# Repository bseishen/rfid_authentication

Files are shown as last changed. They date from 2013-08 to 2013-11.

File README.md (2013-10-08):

# Overview

[Midsouth Makers](www.midsouthmakers.org) RFID access based on a [Beagle Bone Black](http://beagleboard.org/Products/BeagleBone%20Black) and a cheap Chinese wiegand reader.

# How To

## Add user
You must be a part of the administrator group to add users.

### Via the Keypad
Scan rfid token and enter your 4 digit pin.
Press the 3 key. Light will flash green and beep once completed. This will enter add user mode. Esc can be hit to exit this mode.
Scan the new RFID token, and have user enter a 4 digit pin.
Light will flash green and beep once completed successfully.

### Via the Web Interface
TODO: add content

## Delete user
You must be a part of the administrator group to add users.

### Via the Keypad
Scan rfid token and enter your 4 digit pin.
Press the 4 key. Light will flash green and beep once completed. This will enter add user mode. Esc can be hit to exit this mode.
Scan the new RFID token, and have user enter a 4 digit pin.
Light will flash green and beep once completed successfully.
Technical Details

# Source Code
All Code is located on a github repository located at: https://github.com/bseishen/rfid_authentication/

# Wiegand Reader
Reader is a 26bit Chinese special. MSB and LSB are parity bits, the remainging 24bits are the LSB of the RFID token.

Couple of gotcha's with this reader:
* Numeric key presses are sent without parity and are only 16bits.
* Buzzer lines or status led cannot be held low when trying to read data from the reader.

## Panel
## Pin Assignements
* Relay 1 - `GPIO_67` - Garage Door
* Relay 2 - `GPIO_66` - Front Door
* Relay 3 - `GPIO_44` - Buzzer
* Relay 4 - `GPIO_45` - Status LED
* Relay 5 - `GPIO_26` - UNASSIGNED
* Relay 6 - `GPIO_23` - UNASSIGNED
* Relay 7 - `GPIO_46` - UNASSIGNED
* Relay 8 - `GPIO_47` - Strobe
* `GPIO_68` - Wiegand D0
* `GPIO_69` - Wiegand D1
* `GPIO_02` - 1 wire for temperature sensor

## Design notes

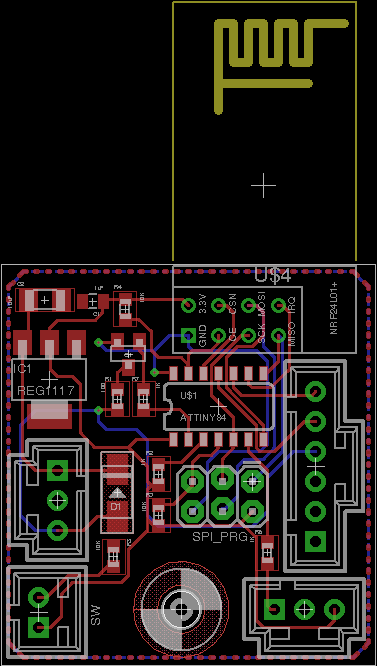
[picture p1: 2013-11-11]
Hardware/Squid_Leg_Controller.png

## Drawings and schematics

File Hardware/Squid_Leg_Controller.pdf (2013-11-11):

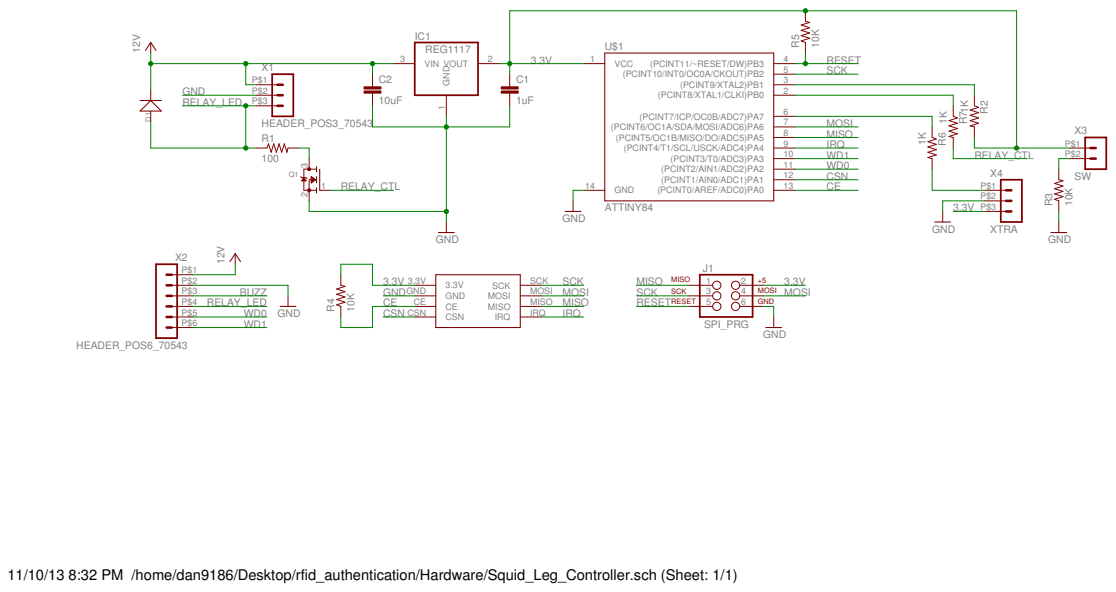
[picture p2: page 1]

11/10/13 8:32 PM /home/dan9186/Desktop/rfid_authentication/Hardware/Squid_Leg_Controller.sch (Sheet: 1/1)

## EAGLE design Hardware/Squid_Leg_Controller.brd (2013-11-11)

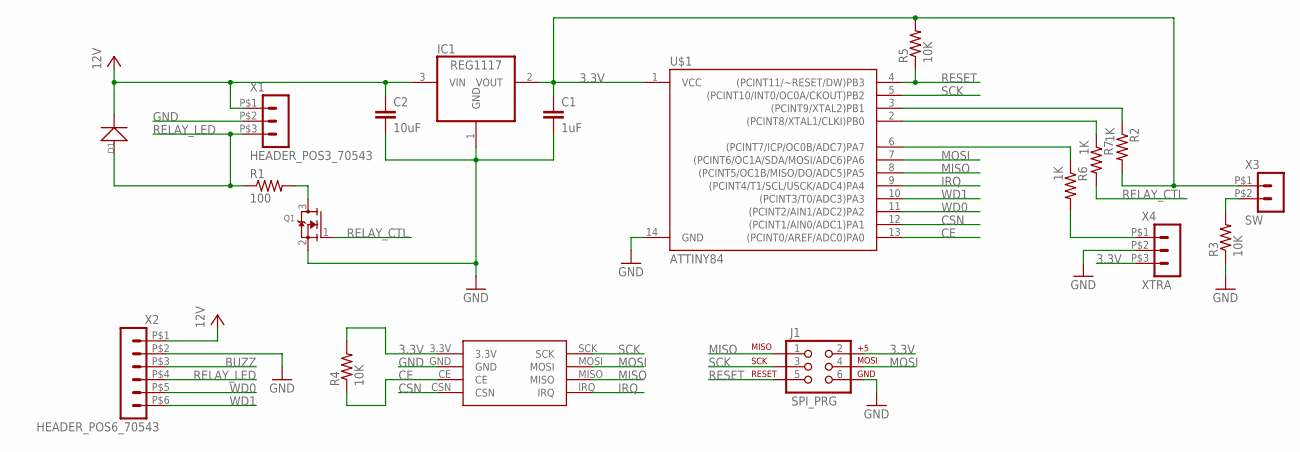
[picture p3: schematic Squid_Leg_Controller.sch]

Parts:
C1: 1uF; 0805
C2: 10uF; 1206
D1: D-SMA; DO-214AC
IC1: REG1117; SOT223
J1: SPI_PRG; 2X3_LOCK
Q1: MOSFET-NREFLOW; SOT23
R1: 100; R0603
R2, R6, R7: 1K; R0603
R3, R4, R5: 10K; R0603
U$1: ATTINY84; SO14
U$4: NRF24L01+; NRF24L01+_MODULE_OFFBRD
X1: HEADER_POS3_70543; 70543-POS3
X2: HEADER_POS6_70543; 70543-POS6
X3: SW; 70543-POS2
X4: XTRA; 70543-POS3

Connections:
3.3V: C1.1, IC1.2 (VOUT), J1.2, R2.2, R4.2, R5.2, U$1.1 (VCC), U$4.3.3V, X3.P$1 (1), X4.P$3 (3)
BUZZ: X2.P$3 (3)
CE: R4.1, U$1.13 ((PCINT0/AREF/ADC0)PA0), U$4.CE
CSN: U$1.12 ((PCINT1/AIN0/ADC1)PA1), U$4.CSN
GND: C1.2, C2.2, IC1.1 (GND), J1.6, Q1.2 (S), R3.1, U$1.14 (GND), U$4.GND, X1.P$2 (2), X2.P$2 (2), X4.P$2 (2)
IRQ: U$1.9 ((PCINT4/T1/SCL/USCK/ADC4)PA4), U$4.IRQ
MISO: J1.1, U$1.8 ((PCINT5/OC1B/MISO/DO/ADC5)PA5), U$4.MISO
MOSI: J1.4, U$1.7 ((PCINT6/OC1A/SDA/MOSI/ADC6)PA6), U$4.MOSI
unnamed: R2.1, U$1.3 ((PCINT9/XTAL2)PB1)
unnamed: R3.2, X3.P$2 (2)
unnamed: R6.1, U$1.6 ((PCINT7/ICP/OC0B/ADC7)PA7)
unnamed: R7.1, U$1.2 ((PCINT8/XTAL1/CLKI)PB0)
unnamed: Q1.3 (D), R1.2
unnamed: R6.2, X4.P$1 (1)
RELAY_CTL: Q1.1 (G), R7.2
RELAY_LED: D1.1 (+), R1.1, X1.P$3 (3), X2.P$4 (4)
RESET: J1.5, R5.1, U$1.4 ((PCINT11/~RESET/DW)PB3)
SCK: J1.3, U$1.5 ((PCINT10/INT0/OC0A/CKOUT)PB2), U$4.SCK
VCC: C2.1, D1.2 (-), IC1.3 (VIN), X1.P$1 (1), X2.P$1 (1)
WD0: U$1.11 ((PCINT2/AIN1/ADC2)PA2), X2.P$5 (5)
WD1: U$1.10 ((PCINT3/T0/ADC3)PA3), X2.P$6 (6)

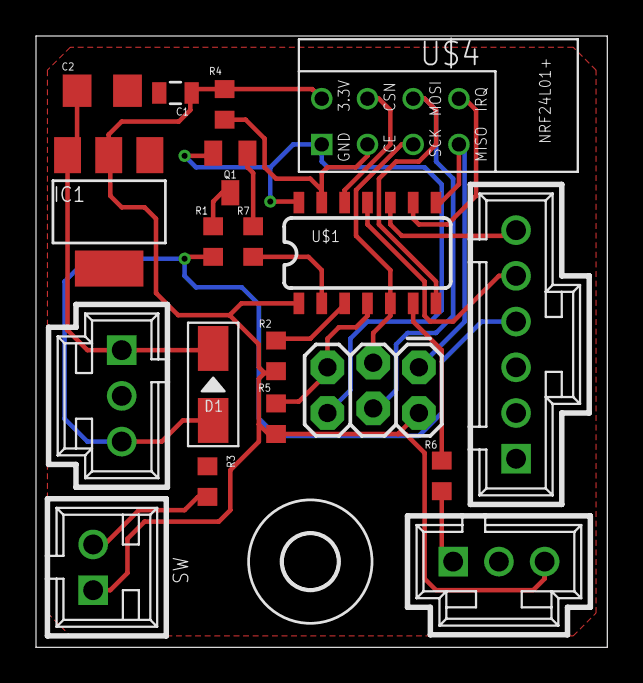
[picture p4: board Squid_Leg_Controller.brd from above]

Board: 2 copper layers, 31.7 x 34.0 mm, 20 parts (0 on the bottom side), 20 nets.

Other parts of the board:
U$2: 3,0

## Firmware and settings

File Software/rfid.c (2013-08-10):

/*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
This library is distributed in the hope that it will be useful,
but WITHOUT ANY WARRANTY; without even the implied warranty of
MERCHANTABILITY or FITNESS FOR A PARTICULAR PURPOSE. See the GNU
Lesser General Public License for more details.
*/
#include <stdio.h>
#include <stdlib.h>
#include <string.h>
#include <errno.h>
#include <unistd.h>
#include <syslog.h>
#include <fcntl.h>
#include <poll.h>
#include <pthread.h>
#include <sys/time.h>
#include <crypt.h>
#include "config.h"
#include "gpio.h"
#include "log.h"
#include "sqlite3.h"

//#define DEBUG_WIEGAND 1
//#define DEBUG	1

#define STATUS_NULL 		0x00
#define STATUS_RFID_READY	0x01
#define STATUS_KEYS_READY	0x02
#define STATUS_AUX_OPTIONS	0x04


pthread_t tid[1];

struct reader_t {
	unsigned char status;				//This is a bit mask field. 0x01-RFID_READY, 0x02-KEYS_READY, 0x04-AUX_OPTIONS_READY
	unsigned int  rfid; 				//RFID key that was read
	unsigned char keys[5];				//Key presses stored in this array
	struct timeval tvPacket; 			//time since the last wiegand packet was recivied, used to timeout the session for inactivity.
};

struct reader_t reader;

unsigned char clear_reader = 0;  		//bit flag used to tell the wiegand routine to flush any temp data.



/**
 * Poll_wiegand polls D0 and D1 for data and fills the reader structure.
 */

void* poll_wiegand(void *arg){
	struct pollfd fdset[2];
	struct timeval tvEnd, tvDiff;
	int nfds = 2;
	int lastPacketType = 0;
	int keyCount=0;
	int temp=0;
	int readerCount=0;
	int gpio_d0, gpio_d1, timePacket, rc;
	char *buf[MAX_BUF];
	char error[255];
	unsigned char charTemp;

	gpio_d0 = gpio_fd_open(WIEGAND_D0_GPIO);
	gpio_d1 = gpio_fd_open(WIEGAND_D1_GPIO);
 
	memset((void*)fdset, 0, sizeof(fdset));

	fdset[0].fd = gpio_d0;
	fdset[0].events = POLLPRI;

	fdset[1].fd = gpio_d1;
	fdset[1].events = POLLPRI;

	//This is needed to flush the first false interrupt
	read(fdset[0].fd, buf, MAX_BUF);
	read(fdset[1].fd, buf, MAX_BUF);

	clear_reader = 1;

	while (1) {
		gettimeofday(&reader.tvPacket, NULL);

		rc = poll(fdset, nfds, -1);

		if (rc < 0) {
			sprintf(error,"Pin interrupt poll failed, fatal error.");
			log_err(error);
		}

		gettimeofday(&tvEnd, NULL);

                timersub(&tvEnd, &reader.tvPacket, &tvDiff);
                timePacket = (tvDiff.tv_sec) * 1000 + (tvDiff.tv_usec) / 1000 ;

		//clear everything if there wasnt a press after 10 seconds.
		if(timePacket>10000)
			clear_reader = 1;

		//packet data over the wiegand is either 26bits for rfid read or 8 bits for a key press.
		//if time from the last packet is under 5ms, treat the last packet as an rfid packet.
		if(lastPacketType == 1){
			//timersub(&tvEnd, &reader.tvPacket, &tvDiff);
			//timePacket = (tvDiff.tv_sec) * 1000 + (tvDiff.tv_usec) / 1000 ;
			lastPacketType = 0;

			if(timePacket < MAX_WIEGAND_PACKET_LENGTH_MS){
				//Delete all key presses. This is a rfid token being read.
				keyCount = 0;
				reader.keys[0] = 0;
				reader.keys[1] = 0;
				reader.keys[2] = 0;
				reader.keys[3] = 0;
				reader.keys[4] = 0;
			}
			else{
				//Last packet was a key press.
				temp = 0;
				readerCount = 0;
				//If an esc key was pressed, clear reader.
				if(reader.keys[0] == 10 || reader.keys[1] == 10 || reader.keys[2] == 10 || reader.keys[3] == 10){
					clear_reader = 1;
#ifdef DEBUG
					printf("ESC KEY WAS PRESSED\n");
#endif
				}
			}
		}

		if(clear_reader == 1){
			reader.status = STATUS_NULL;
			reader.rfid = 0;
			reader.keys[0] = 0;
			reader.keys[1] = 0;
			reader.keys[2] = 0;
			reader.keys[3] = 0;
			reader.keys[4] = 0;
			temp = 0;
			readerCount = 0;
			lastPacketType = 0;
			keyCount = 0;
			clear_reader = 0;
#ifdef DEBUG
			printf("FLUSHING RFID BUFFER\n");
#endif

		}

		//this has been added to flush wiegand trash that shows up from EMI from the door latch.
		if(clear_reader == 2){
#ifdef DEBUG
			printf("ONLY FLUSHING TEMP BUFFER\n");
#endif
			temp = 0;
			readerCount = 0;
			clear_reader = 0;
		}


		if (fdset[0].revents & POLLPRI) {
			read(fdset[0].fd, buf, MAX_BUF);
			temp = temp << 1;
			readerCount++;
		}

		if (fdset[1].revents & POLLPRI) {
			read(fdset[1].fd, buf, MAX_BUF);
			temp = temp << 1;
			temp |= 1;
			readerCount++;
		}


		///Key was pressed, add it to the array
		if(readerCount==WIEGAND_KEY_LENGTH){
			if(keyCount>5){
				keyCount=0;
				reader.status  &= ~(STATUS_KEYS_READY|STATUS_AUX_OPTIONS);
#ifdef DEBUG
				printf("KEY PRESSES EXCEEDED 5 PRESSES, FLUSHING KEY BUFFER\n");
#endif
				fflush(stdout);
			}

			switch(temp){
				case 0xE1:
					charTemp = 1;
					break;
				case 0xD2:
					charTemp = 2;
					break;
				case 0xC3:
					charTemp = 3;
					break;
				case 0xB4:
					charTemp = 4;
					break;
				case 0xA5:
					charTemp = 5;
					break;
				case 0x96:
					charTemp = 6;
					break;
				case 0x87:
					charTemp = 7;
					break;
				case 0x78:
					charTemp = 8;
					break;
				case 0x69:
					charTemp = 9;
					break;
				case 0xF0:
					charTemp = 0;
					break;
				case 0x5A:
					charTemp = 10;
					break;
				case 0x4B:
					charTemp = 11;
					break;
				default:
					charTemp = 0xFF; //DATA WAS GARBAGE
			}

			if(charTemp!=0xFF){
				reader.keys[keyCount] = charTemp;
				//set status bit for keyRead is ready
				if(keyCount == 3){
					reader.status |= STATUS_KEYS_READY;
#ifdef DEBUG
					printf("4 Keys in Buffer \n");
#endif
				}
				if(keyCount == 4){
					reader.status |= STATUS_AUX_OPTIONS;
#ifdef DEBUG
					printf("5 Keys in Buffer \n");
#endif
				}
			}

			keyCount++;
			lastPacketType = 1;
		}

		///RFID data is present, store it.
		if(readerCount == 26){
			//Mask the MSB off and Shift out the LSB. These are the even and odd parity.
			reader.rfid=(temp>>1) & 0x00FFFFFF;
			reader.status |= STATUS_RFID_READY;
			readerCount = 0;
			temp = 0;
			keyCount = 0;
			reader.keys[0] = 0;
			reader.keys[1] = 0;
			reader.keys[2] = 0;
			reader.keys[3] = 0;
			reader.keys[4] = 0;
		}

		if(readerCount > 26){
			//something went wrong
			clear_reader = 1;
		}

#ifdef DEBUG_WIEGAND
		printf("RFID: %X \n", reader.rfid);
		printf("KEYCOUNT: %X \n", keyCount);
		printf("KEY1: %X \n", reader.keys[0]);
		printf("KEY2: %X \n", reader.keys[1]);
		printf("KEY3: %X \n", reader.keys[2]);
		printf("KEY4: %X \n", reader.keys[3]);
		printf("KEY5: %X \n", reader.keys[4]);
		printf("STATUS: %X \n\n", reader.status);
#endif



		fflush(stdout);

	}

	gpio_fd_close(gpio_d0);
	gpio_fd_close(gpio_d1);

}

int main(int argc, char **argv, char **envp)
{

	int retval;
	unsigned char userVerified = 0; 			//0- Not verified, 1-verified, 2-verified as admin
	unsigned int lastKey;
	char *result;
	char buffer[20];
	char hash[40] = "$1$DeaDBeeF$NanaNanaBooBoo//DooDoo";
	char query[200];
	char error[255];
	sqlite3_stmt *stmt;
	sqlite3 *handle;
	struct timeval tvNow, tvDifference, tvAux, tvUnlock;
	int timeMS;
	int keyBuff;


	//init ports
	gpio_init();

	//init tvUnlock, last time of door unlock.
	gettimeofday(&tvUnlock, NULL);

	//init DB
    retval = sqlite3_open(DB_PATH, &handle);
    if(retval)
    {
		sprintf(error,"Sqlite DB failed to INIT!");
		log_err(error);
        return -1;
    }

    sprintf(query,"CREATE TABLE IF NOT EXISTS users (key INTERGER PRIMARY KEY,hash TEXT NOT NULL, ircName TEXT, spokenName TEXT, addedBy TEXT, dateCreated INTERGER, isAdmin INTERGER, lastLogin INTERGER, isActive INTERGER)");
    retval = sqlite3_exec(handle,query,0,0,0);


    //Thread off wiegand poller
	if (pthread_create(&(tid[1]), NULL, &poll_wiegand, NULL)){
		sprintf(error,"Wiegand thread failed to start.");
		log_err(error);
	}


	fflush(stdout);

	while(1){
		usleep(500000);

		//get time passed since last wiegand packet
		gettimeofday(&tvNow, NULL);
		timersub(&tvNow, &tvUnlock, &tvDifference);
		timeMS = (tvDifference.tv_sec) * 1000 + (tvDifference.tv_usec) / 1000 ;
#ifdef DEBUG
//		printf("Timer: %d",timeMS);
#endif
		///Clear if timeout has exceeded threshold. Lock everything!
		if(timeMS>TIMEOUT_DOORLOCK && userVerified > 0){
			lock_door();
			led_off();
			beep_off();
			usleep(250000);
			printf("DOOR LOCKING!!!!!!!!!!!!!!\n");
			clear_reader = 1;
			userVerified = 0;
		}
#ifdef DEBUG
		//printf("READER STATUS: %d \n",reader.status);
#endif
		//Authenticate User
		if(userVerified == 0 && clear_reader == 0 &&(reader.status == (STATUS_RFID_READY|STATUS_KEYS_READY) || reader.status == (STATUS_RFID_READY|STATUS_KEYS_READY|STATUS_AUX_OPTIONS))){
			keyBuff = (reader.keys[0]*1000)+(reader.keys[1]*100)+(reader.keys[2]*10)+reader.keys[3];
			sprintf(query, "SELECT * from users WHERE key='%d'" , reader.rfid);
			retval = sqlite3_prepare_v2(handle,query,-1,&stmt,0);
			if(retval){
				sprintf(error,"Query returned and error.");
				log_err(error);
			}
			else{

				while(1)
				    {
				        retval = sqlite3_step(stmt);

				        if(retval == SQLITE_ROW)
				        {
				        	const char *val = (char *)sqlite3_column_text(stmt,1);
				        	sprintf(hash, "%s", val);
				        }
				        else if(retval == SQLITE_DONE)
				        {
				            // All rows finished
				            break;
				        }
				        else
				        {
				            // Some error encountered
							sprintf(error,"SQLite shit the bed.");
							log_err(error);
				        }
				    }

				sprintf(buffer, "%d", keyBuff);
				result = crypt(buffer, hash);
				sprintf(query, "SELECT * from users WHERE key='%d'" , reader.rfid);
				retval = sqlite3_exec(handle,query,0,0,0);
				if(retval){
					sprintf(error,"Query returned and error.");
					log_err(error);
				}
				else{
					while(1){
						// fetch a row's status
						retval = sqlite3_step(stmt);

						if(retval == SQLITE_ROW){
				        	const char *val = (char *)sqlite3_column_text(stmt,1);
				        	sprintf(hash, "%s", val);
				        	if(strcmp(hash,result)==0){
				        		//Check if user is active.
				        		if(sqlite3_column_int(stmt,8)){
				        			userVerified= 1;
				        			//Check if user is an admin.
				        			if(sqlite3_column_int(stmt,6)){
				        				userVerified = 2;
				        			}
				        		}
				        	}
						}
						else if(retval == SQLITE_DONE){
							// All rows finished
							break;
						}
						else{
							// Some error encountered
							sprintf(error,"SQLite shit the bed.");
							log_err(error);
							return -1;
						}
					}
				}


				if(userVerified > 0){
					sprintf(error,"Access granted to user %d", reader.rfid);
					log_err(error);
					//clear temp buffer and grab last rfid key
					lastKey=reader.rfid;
					//Possibly need to clear reader temp

					//Update User's last login time
					sprintf(query, "UPDATE users SET lastLogin='%d' WHERE key='%d'" ,(int)tvNow.tv_sec, reader.rfid);
					retval = sqlite3_prepare_v2(handle,query,-1,&stmt,0);
					if(retval){
						sprintf(error,"Query returned and error.");
						log_err(error);
					}

					retval = sqlite3_step(stmt);

					gettimeofday(&tvUnlock, NULL);

					unlock_door();
					usleep(100000);
					clear_reader = 2;
					//led_on();

					//TODO:log user in logs, notify irc, play welcome message.

				}
				else{
					sprintf(error,"ACCESS DENIED to user %d", reader.rfid);
					log_err(error);
					clear_reader = 1;
					led_blink(2);
				}
			}
		}

		//delete user (using 4 key on keypad)
		if(userVerified == 2 && reader.keys[4]==4){
			lastKey = reader.rfid;
			sprintf(error,"Delete user mode entered by user ID: %d", reader.rfid);
			log_err(error);
			clear_reader = 1;
			beep_on();
			sleep(1);
			beep_off();

			//Wait for rfid to be scanned. Cancels if ESC key is pressed.
			while(reader.status!= (STATUS_RFID_READY|STATUS_KEYS_READY)){
				if(reader.keys[0]==10 || reader.keys[1]==10 ||reader.keys[2]==10 ||reader.keys[3]==10 ||reader.keys[4]==10){
					retval = 1;
					break;
				}

				gettimeofday(&tvAux, NULL);
				timersub(&tvAux, &tvNow, &tvDifference);
				timeMS = (tvDifference.tv_sec) * 1000 + (tvDifference.tv_usec) / 1000 ;
				if(timeMS > 20000){
					retval = 1;
					break;
				}

				sleep(.1);

			}

			//if ESC key was pressed or if admin key was scanned twice.
			if(retval || reader.rfid == lastKey){
				sprintf(error,"Delete user mode exited by %d. No user deleted.",reader.rfid);
				log_err(error);
			}
			else{
				sprintf(query, "DELETE FROM users WHERE key='%d'" , reader.rfid);
				retval = sqlite3_prepare_v2(handle,query,-1,&stmt,0);
				retval = sqlite3_step(stmt);

				if(retval == SQLITE_DONE){
					sprintf(error,"User %d deleted from DB by User %d",reader.rfid, lastKey);
					log_err(error);
				}

				beep_on();
				sleep(1);
				beep_off();
			}

			clear_reader = 1;
			fflush(stdout);
		}
#ifdef ADD_FIRST_USER
		userVerified = 2;
		reader.keys[4]=11;
#endif
		//add new user (using 3 key on keypad)
		if(userVerified == 2 && reader.keys[4]==3){
			lastKey = reader.rfid;

			sprintf(error,"Add user mode entered by user %d",reader.rfid);
			log_err(error);

			clear_reader = 1;
			beep_on();
			sleep(1);
			beep_off();

			retval = 0;
			//Wait for rfid and keys to be pressed for the new user. Cancels if ESC key is pressed or takes longer than 20sec.
			while(reader.status!=(STATUS_RFID_READY|STATUS_KEYS_READY)){
				if(reader.keys[0]==10 || reader.keys[1]==10 ||reader.keys[2]==10 ||reader.keys[3]==10 ||reader.keys[4]==10){
					retval = 1;
					break;
				}

				gettimeofday(&tvAux, NULL);
				timersub(&tvAux, &tvNow, &tvDifference);
				timeMS = (tvDifference.tv_sec) * 1000 + (tvDifference.tv_usec) / 1000 ;
				if(timeMS > 20000){
					retval = 1;
					break;
				}

				sleep(.1);

			}

			//if ESC key was pressed
			if(retval || reader.rfid == lastKey){
				sprintf(error,"Add user mode exited, no users were added.");
				log_err(error);
			}
			else{
				unsigned long seed[2];
			    char salt[] = "$1$........";
			    const char *const seedchars ="./0123456789ABCDEFGHIJKLMNOPQRSTUVWXYZabcdefghijklmnopqrstuvwxyz";
			    int i;

			    /* Generate a (not very) random seed.
			       You should do it better than this... */
			    seed[0] = time(NULL);
			    seed[1] = getpid() ^ (seed[0] >> 14 & 0x30000);

			    /* Turn it into printable characters from `seedchars'. */
			    for (i = 0; i < 8; i++)
			      salt[3+i] = seedchars[(seed[i/5] >> (i%5)*6) & 0x3f];


				keyBuff = (reader.keys[0]*1000)+(reader.keys[1]*100)+(reader.keys[2]*10)+reader.keys[3];

				sprintf(buffer, "%d", keyBuff);
				result = crypt(buffer, salt);

#ifdef ADD_FIRST_USER
				sprintf(query, "INSERT INTO users VALUES('%d','%s','','','%d','%d',1,0,1)" , reader.rfid, result, lastKey, (int)tvNow.tv_sec);
#else
				sprintf(query, "INSERT INTO users VALUES('%d','%s','','','%d','%d',0,0,1)" , reader.rfid, result, lastKey, (int)tvNow.tv_sec);
#endif
				retval = sqlite3_prepare_v2(handle,query,-1,&stmt,0);
				retval = sqlite3_step(stmt);

				if(retval == SQLITE_DONE){
					sprintf(error,"User %d was added to the DB by user %d", reader.rfid, lastKey);
					log_err(error);
				}

				beep_on();
				sleep(1);
				beep_off();

			}
			clear_reader = 1;
		}

		//OpenGarageDoor (using number 2 on keypad)
		if(userVerified > 0 && reader.keys[4]==2){
			sprintf(error,"Garage door toggled by user %d", reader.rfid);
			log_err(error);
			clear_reader = 1;
			toggle_garage();
		}


		fflush(stdout);

	}

	pthread_join(tid[1], NULL);

	sqlite3_close(handle);

	return 0;
}

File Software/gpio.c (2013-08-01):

/*
 * All rights reserved.
 * 
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
 * THIS SOFTWARE IS PROVIDED BY RIDGERUN ''AS IS'' AND ANY
 * EXPRESS OR IMPLIED WARRANTIES, INCLUDING, BUT NOT LIMITED TO, THE IMPLIED
 * WARRANTIES OF MERCHANTABILITY AND FITNESS FOR A PARTICULAR PURPOSE ARE
 * DISCLAIMED. IN NO EVENT SHALL RIDGERUN BE LIABLE FOR ANY
 * DIRECT, INDIRECT, INCIDENTAL, SPECIAL, EXEMPLARY, OR CONSEQUENTIAL DAMAGES
 * (INCLUDING, BUT NOT LIMITED TO, PROCUREMENT OF SUBSTITUTE GOODS OR SERVICES;
 * LOSS OF USE, DATA, OR PROFITS; OR BUSINESS INTERRUPTION) HOWEVER CAUSED AND
 * ON ANY THEORY OF LIABILITY, WHETHER IN CONTRACT, STRICT LIABILITY, OR TORT
 * (INCLUDING NEGLIGENCE OR OTHERWISE) ARISING IN ANY WAY OUT OF THE USE OF THIS
 * SOFTWARE, EVEN IF ADVISED OF THE POSSIBILITY OF SUCH DAMAGE.
 */

#include "gpio.h"

 /****************************************************************
 * Constants
 ****************************************************************/
 
#define SYSFS_GPIO_DIR "/sys/class/gpio"
#define POLL_TIMEOUT (3 * 1000) /* 3 seconds */
#define MAX_BUF 64

/****************************************************************
 * gpio_export
 ****************************************************************/
int gpio_export(unsigned int gpio)
{
	int fd,len;
	char buf[MAX_BUF];
 
	fd = open(SYSFS_GPIO_DIR "/export", O_WRONLY);
	if (fd < 0) {
		perror("gpio/export");
		return fd;
	}
 
	len = snprintf(buf, sizeof(buf), "%d", gpio);
	write(fd, buf, len);
	close(fd);
 
	return 0;
}

/****************************************************************
 * gpio_unexport
 ****************************************************************/
int gpio_unexport(unsigned int gpio)
{
	int fd, len;
	char buf[MAX_BUF];
 
	fd = open(SYSFS_GPIO_DIR "/unexport", O_WRONLY);
	if (fd < 0) {
		perror("gpio/export");
		return fd;
	}
 
	len = snprintf(buf, sizeof(buf), "%d", gpio);
	write(fd, buf, len);
	close(fd);
	return 0;
}

/****************************************************************
 * gpio_set_dir
 ****************************************************************/
int gpio_set_dir(unsigned int gpio, unsigned int out_flag)
{
	int fd;
	char buf[MAX_BUF];
 
	snprintf(buf, sizeof(buf), SYSFS_GPIO_DIR  "/gpio%d/direction", gpio);
 
	fd = open(buf, O_WRONLY);
	if (fd < 0) {
		perror("gpio/direction");
		return fd;
	}
 
	if (out_flag)
		write(fd, "out", 4);
	else
		write(fd, "in", 3);
 
	close(fd);
	return 0;
}

/****************************************************************
 * gpio_set_value
 ****************************************************************/
int gpio_set_value(unsigned int gpio, unsigned int value)
{
	int fd;
	char buf[MAX_BUF];
 
	snprintf(buf, sizeof(buf), SYSFS_GPIO_DIR "/gpio%d/value", gpio);
 
	fd = open(buf, O_WRONLY);
	if (fd < 0) {
		perror("gpio/set-value");
		return fd;
	}
 
	if (value)
		write(fd, "1", 2);
	else
		write(fd, "0", 2);
 
	close(fd);
	return 0;
}

/****************************************************************
 * gpio_get_value
 ****************************************************************/
int gpio_get_value(unsigned int gpio, unsigned int *value)
{
	int fd;
	char buf[MAX_BUF];
	char ch;

	snprintf(buf, sizeof(buf), SYSFS_GPIO_DIR "/gpio%d/value", gpio);
 
	fd = open(buf, O_RDONLY);
	if (fd < 0) {
		perror("gpio/get-value");
		return fd;
	}
 
	read(fd, &ch, 1);

	if (ch != '0') {
		*value = 1;
	} else {
		*value = 0;
	}
 
	close(fd);
	return 0;
}


/****************************************************************
 * gpio_set_edge
 ****************************************************************/

int gpio_set_edge(unsigned int gpio, char *edge)
{
	int fd;
	char buf[MAX_BUF];

	snprintf(buf, sizeof(buf), SYSFS_GPIO_DIR "/gpio%d/edge", gpio);
 
	fd = open(buf, O_WRONLY);
	if (fd < 0) {
		perror("gpio/set-edge");
		return fd;
	}
 
	write(fd, edge, strlen(edge) + 1); 
	close(fd);
	return 0;
}

/****************************************************************
 * gpio_fd_open
 ****************************************************************/

int gpio_fd_open(unsigned int gpio)
{
	int fd;
	char buf[MAX_BUF];

	snprintf(buf, sizeof(buf), SYSFS_GPIO_DIR "/gpio%d/value", gpio);
 
	fd = open(buf, O_RDONLY | O_NONBLOCK );
	if (fd < 0) {
		perror("gpio/fd_open");
	}
	return fd;
}

/****************************************************************
 * gpio_fd_close
 ****************************************************************/

int gpio_fd_close(int fd)
{
	return close(fd);
}


int gpio_init(void){
        gpio_export(DOOR_GPIO);
        gpio_export(GARAGE_GPIO);
        gpio_export(WIEGAND_D0_GPIO);
        gpio_export(WIEGAND_D1_GPIO);
        gpio_export(STATUS_LED_GPIO);
        gpio_export(BUZZER_GPIO);

        gpio_set_dir(DOOR_GPIO, 1);
        gpio_set_dir(GARAGE_GPIO, 1);
        gpio_set_dir(WIEGAND_D0_GPIO, 0);
        gpio_set_dir(WIEGAND_D1_GPIO, 0);
        gpio_set_dir(STATUS_LED_GPIO, 1);
        gpio_set_dir(BUZZER_GPIO, 1);

        gpio_set_edge(WIEGAND_D0_GPIO, "falling");
        gpio_set_edge(WIEGAND_D1_GPIO, "falling");

        gpio_set_value(DOOR_GPIO, 1);
        gpio_set_value(GARAGE_GPIO, 1);
        gpio_set_value(STATUS_LED_GPIO, 1);
        gpio_set_value(BUZZER_GPIO, 1);

	return 1;
}

/**
 * Activates the beeper on the reader.
 */
void beep_on(){
	gpio_set_value(BUZZER_GPIO, 0);
}

/**
 * Turns off the beeper on the reader.
 */
void beep_off(){
	gpio_set_value(BUZZER_GPIO, 1);
}

/**
 * Activates the led on the reader.
 */
void led_on(){
	gpio_set_value(STATUS_LED_GPIO, 0);
}

/**
 * Turns off the led on the reader.
 */
void led_off(){
	gpio_set_value(STATUS_LED_GPIO, 1);
}

/**
 * Turns off and on the led on the reader.
 */
void led_blink(int times){
	int i;
	for(i=0; i<times; i++){
		led_on();
		sleep(.5);
		led_off();
		sleep(.5);
	}
}

/**
 * Self Explanatory.
 */
void unlock_door(){
	gpio_set_value(DOOR_GPIO, 0);
}

/**
 * Self Explanatory.
 */
void lock_door(){
	gpio_set_value(DOOR_GPIO, 1);
}

/**
 * Toggles Garage door.
 */
void toggle_garage(){
	gpio_set_value(GARAGE_GPIO, 0);
	sleep(1);
	gpio_set_value(GARAGE_GPIO, 1);
}

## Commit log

2013-07-16 New things to test. fixed some compile warnings.
    [rfid.c]
2013-08-07 Attempt to fix broken keypad reads. .gitignore revamped
    [config.h, rfid.c]
2013-08-07 Changed key pad functions. Esc will flush reader buffers, 3 will add a user, 4 will delete user.
2013-08-07 Added exception to flush temp buffer. Hopefully this will clear up the wiegand trash due to EMI interface from door latch.
    [rfid.c]
2013-08-07 Fixed logic issue with adding/removing users.
    [rfid.c]
2013-08-07 Completed README.md, removed unessacary files thread.bak, wiegand.bak
2013-08-09 Now working, Had to fix issues with clearing the buffer after garbage was sent on the wiegand bus due to EMI
    [rfid.c]
2013-11-07 initializing hardware section
    [Squid_Leg_Controller.brd, Squid_Leg_Controller.sch]
2013-11-08 saving progress on adding in buzzer and led controls
    [Squid_Leg_Controller.brd, Squid_Leg_Controller.sch]
2013-11-08 routed remainig pieces, added in mosfet to control LED and buzzer, and attached DRU
    [Squid_Leg_Controller.brd, Squid_Leg_Controller.sch]
2013-11-08 exported previews of current revisions
2013-11-09 updated missing resistors and removed traces on board, tracing needs to be redone
    [Squid_Leg_Controller.brd, Squid_Leg_Controller.sch]
2013-11-10 added button and rerouted board
    [Squid_Leg_Controller.brd, Squid_Leg_Controller.sch]
2013-11-11 slight adjustment to board, better silk screen, changed switch to locking connector, broke out extra IO, and moved mounting hole
    [Squid_Leg_Controller.brd, Squid_Leg_Controller.sch]

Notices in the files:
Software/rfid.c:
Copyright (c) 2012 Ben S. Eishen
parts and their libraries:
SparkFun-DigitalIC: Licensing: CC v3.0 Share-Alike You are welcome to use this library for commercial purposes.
